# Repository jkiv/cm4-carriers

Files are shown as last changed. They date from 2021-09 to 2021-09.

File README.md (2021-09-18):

# cm4-carriers

## About

This repository contains various Raspberry Pi Compute Module 4 (CM4) carrier boards designed with specific applications in mind.

It also contains "template" boards from which application-specific boards can be quickly derived.

## Boards

### cm4-carrier-net

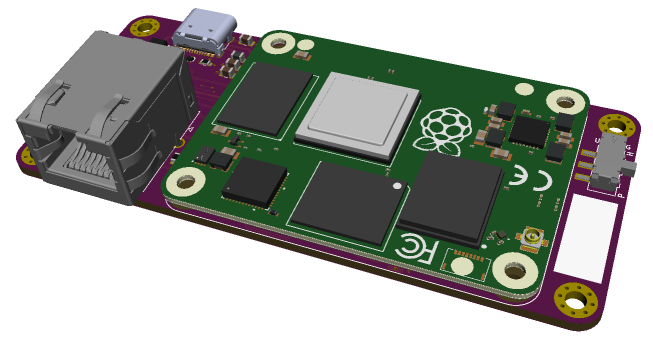
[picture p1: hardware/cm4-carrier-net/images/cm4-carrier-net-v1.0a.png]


#### About
A carrier board that provides the CM4 with an Ethernet interface.

This board can also be used to program the eMMC memory for use on other carrier boards.

#### Features
* Gigabit Ethernet
* USB Type-C 5V power and data (USB 2.0)
* Micro SD card slot

## Donate

Please consider supporting this project and others like it by donating:

* ☕: [ko-fi.com/jkiv_](https://ko-fi.com/jkiv_)
* ₿: `13zRrs1YDdooUN5WtfXRSDn8KnJdok4qG9`

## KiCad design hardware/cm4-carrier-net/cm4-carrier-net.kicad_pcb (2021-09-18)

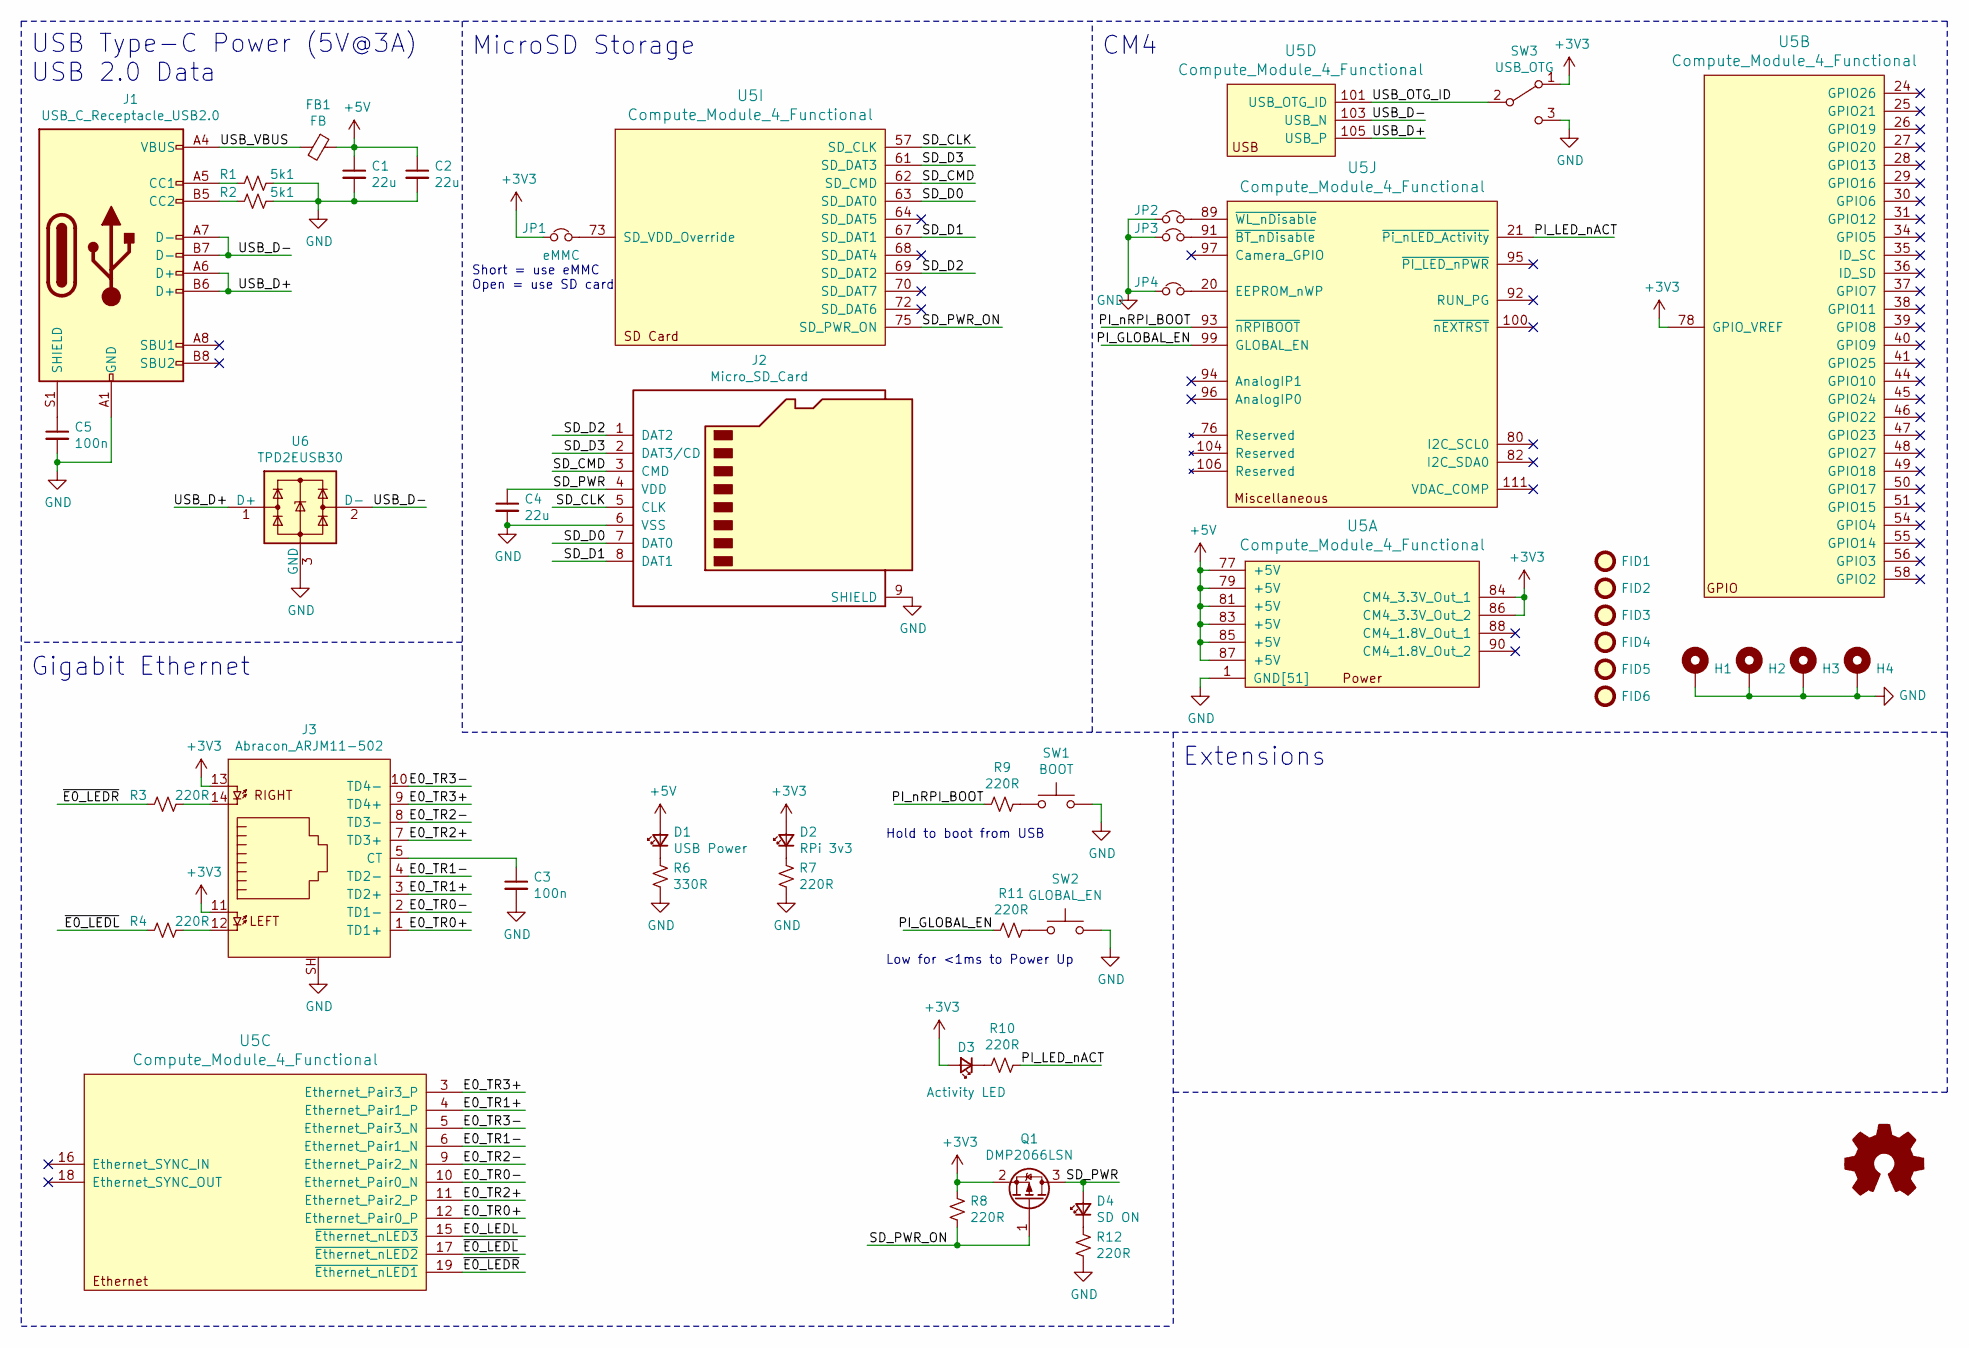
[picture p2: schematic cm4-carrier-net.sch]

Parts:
C1, C2, C4: 22u; C_0805_2012Metric
C3, C5: 100n; C_0805_2012Metric
D1: USB Power; LED_0603_1608Metric
D2: RPi 3v3; LED_0603_1608Metric
D3: Activity LED; LED_0603_1608Metric
D4: SD ON; LED_0603_1608Metric
FB1: FB; L_0805_2012Metric
FID1, FID2, FID3, FID4, FID5, FID6: Fiducial; Fiducial_0.75mm_Mask1.5mm
H1, H2, H3, H4: MountingHole_Pad; MountingHole_2.7mm_M2.5_Pad_Via
J1: USB_C_Receptacle_USB2.0; USB_C_Receptacle_GCT-USB4105
J2: Micro_SD_Card; microSD_HC_Molex_104031-0811
J3: Abracon_ARJM11-502; RJ45_Abracon_ARJM11
JP1: eMMC; J_Small_NC
JP2: ~WL_nDisable; J_Small_NC
JP3: ~BT_nDisable; J_Small_NC
JP4: EEPROM_nWP; J_Small_NC
LOGO1: Logo_Open_Hardware_Small; OSHW-Symbol_6.7x6mm_Copper
Q1: DMP2066LSN; SC-59
R1, R2: 5k1; R_0603_1608Metric
R3, R4, R7, R8, R9, R10, R11, R12: 220R; R_0603_1608Metric
R6: 330R; R_0603_1608Metric
SW1: BOOT; SW_SPST_B3U-1000P
SW2: GLOBAL_EN; SW_SPST_B3U-1000P
SW3: USB_OTG; SW_SPDT_CK-JS102011SAQN
U5: Compute_Module_4_Functional; Raspberry-Pi-4-Compute-Module
U6: TPD2EUSB30; Texas_DRT-3

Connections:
+3V3: D2.2 (A), D3.2 (A), J3.11, J3.13, JP1.1, Q1.2 (S), R8.2, SW3.1 (A), U5.78 (GPIO_VREF), U5.84 (CM4_3.3V_Out_1), U5.86 (CM4_3.3V_Out_2)
+5V: C1.1, C2.1, D1.2 (A), FB1.1, U5.77 (+5V), U5.79 (+5V), U5.81 (+5V), U5.83 (+5V), U5.85 (+5V), U5.87 (+5V)
/E0_LEDL: U5.15 (~Ethernet_nLED3)
/E0_TR0+: J3.1 (TD1+), U5.12 (Ethernet_Pair0_P)
/E0_TR0-: J3.2 (TD1-), U5.10 (Ethernet_Pair0_N)
/E0_TR1+: J3.3 (TD2+), U5.4 (Ethernet_Pair1_P)
/E0_TR1-: J3.4 (TD2-), U5.6 (Ethernet_Pair1_N)
/E0_TR2+: J3.7 (TD3+), U5.11 (Ethernet_Pair2_P)
/E0_TR2-: J3.8 (TD3-), U5.9 (Ethernet_Pair2_N)
/E0_TR3+: J3.9 (TD4+), U5.3 (Ethernet_Pair3_P)
/E0_TR3-: J3.10 (TD4-), U5.5 (Ethernet_Pair3_N)
/PI_GLOBAL_EN: R11.2, U5.99 (GLOBAL_EN)
/PI_LED_nACT: R10.1, U5.21 (~Pi_nLED_Activity)
/PI_nRPI_BOOT: R9.2, U5.93 (~nRPIBOOT)
/SD_CLK: J2.5 (CLK), U5.57 (SD_CLK)
/SD_CMD: J2.3 (CMD), U5.62 (SD_CMD)
/SD_D0: J2.7 (DAT0), U5.63 (SD_DAT0)
/SD_D1: J2.8 (DAT1), U5.67 (SD_DAT1)
/SD_D2: J2.1 (DAT2), U5.69 (SD_DAT2)
/SD_D3: J2.2 (DAT3/CD), U5.61 (SD_DAT3)
/SD_PWR: C4.1, D4.2 (A), J2.4 (VDD), Q1.3 (D)
/SD_PWR_ON: Q1.1 (G), R8.1, U5.75 (SD_PWR_ON)
/USB_D+: J1.A6 (D+), J1.B6 (D+), U5.105 (USB_P), U6.1 (D+)
/USB_D-: J1.A7 (D-), J1.B7 (D-), U5.103 (USB_N), U6.2 (D-)
/USB_OTG_ID: SW3.2 (B), U5.101 (USB_OTG_ID)
/USB_VBUS: FB1.2, J1.A4 (VBUS), J1.A9 (VBUS), J1.B4 (VBUS), J1.B9 (VBUS)
/~E0_LEDL: R4.2, U5.17 (~Ethernet_nLED2)
/~E0_LEDR: R3.2, U5.19 (~Ethernet_nLED1)
GND: C1.2, C2.2, C3.2, C4.2, C5.2, H1.1, H2.1, H3.1, H4.1, J1.A1 (GND), J1.A12 (GND), J1.B1 (GND), J1.B12 (GND), J2.6 (VSS), J2.9 (SHIELD), J3.SH, JP2.1, JP3.1, JP4.1, R1.1, R2.1, R6.2, R7.2, R12.2, SW1.2, SW2.2, SW3.3 (C), U5.1 (GND[51]), U5.2 (GND[51]), U5.7 (GND[51]), U5.8 (GND[51]), U5.13 (GND[51]), U5.14 (GND[51]), U5.22 (GND[51]), U5.23 (GND[51]), U5.32 (GND[51]), U5.33 (GND[51]), U5.42 (GND[51]), U5.43 (GND[51]), U5.52 (GND[51]), U5.53 (GND[51]), U5.59 (GND[51]), U5.60 (GND[51]), U5.65 (GND[51]), U5.66 (GND[51]), U5.71 (GND[51]), U5.74 (GND[51]), U5.98 (GND[51]), U5.107 (GND[51]), U5.108 (GND[51]), U5.113 (GND[51]), U5.114 (GND[51]), U5.119 (GND[51]), U5.120 (GND[51]), U5.125 (GND[51]), U5.126 (GND[51]), U5.131 (GND[51]), U5.132 (GND[51]), U5.137 (GND[51]), U5.138 (GND[51]), U5.144 (GND[51]), U5.150 (GND[51]), U5.155 (GND[51]), U5.156 (GND[51]), U5.161 (GND[51]), U5.162 (GND[51]), U5.167 (GND[51]), U5.168 (GND[51]), U5.173 (GND[51]), U5.174 (GND[51]), U5.179 (GND[51]), U5.180 (GND[51]), U5.185 (GND[51]), U5.186 (GND[51]), U5.191 (GND[51]), U5.192 (GND[51]), U5.197 (GND[51]), U5.198 (GND[51]), U6.3 (GND)
unnamed: C3.1, J3.5 (CT), J3.6 (CT)
unnamed: C5.1, J1.S1 (SHIELD)
unnamed: D1.1 (K), R6.1
unnamed: D2.1 (K), R7.1
unnamed: D3.1 (K), R10.2
unnamed: D4.1 (K), R12.1
unnamed: J1.A5 (CC1), R1.2
unnamed: J1.B5 (CC2), R2.2
unnamed: J3.12, R4.1
unnamed: J3.14, R3.1
unnamed: JP1.2, U5.73 (SD_VDD_Override)
unnamed: JP2.2, U5.89 (~WL_nDisable)
unnamed: JP3.2, U5.91 (~BT_nDisable)
unnamed: JP4.2, U5.20 (EEPROM_nWP)
unnamed: R9.1, SW1.1
unnamed: R11.1, SW2.1

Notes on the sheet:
USB Type-C Power (5V@3A) USB 2.0 Data
MicroSD Storage
CM4
Gigabit Ethernet
Extensions
Low for <1ms to Power Up
Short = use eMMC Open = use SD card
Hold to boot from USB

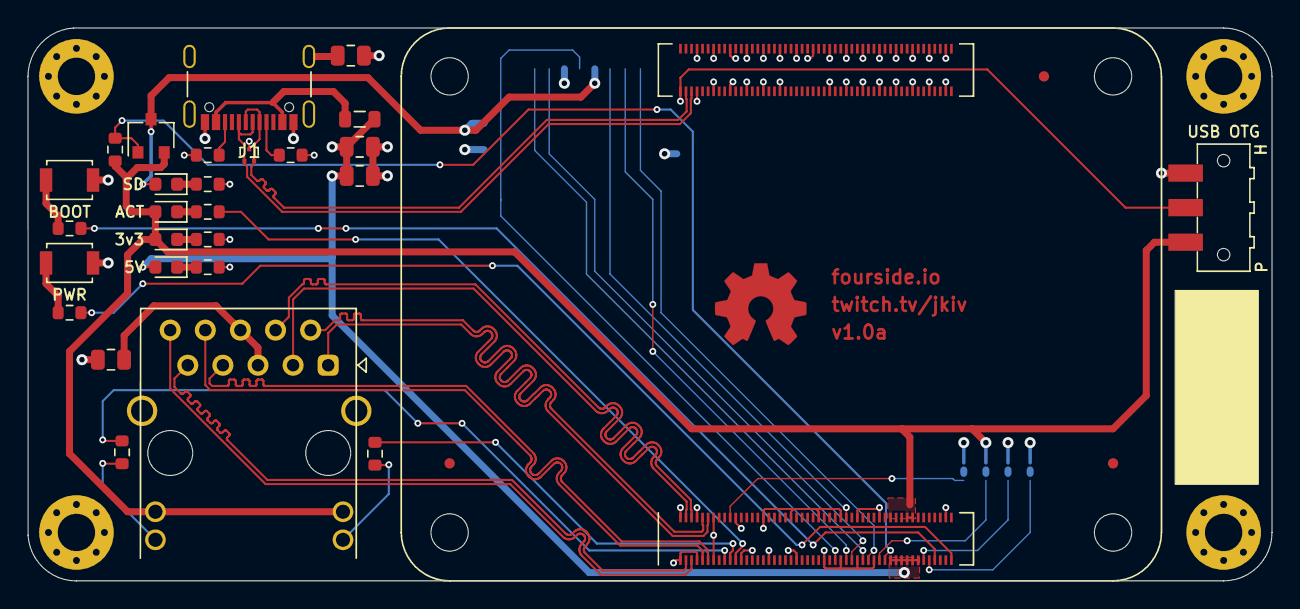
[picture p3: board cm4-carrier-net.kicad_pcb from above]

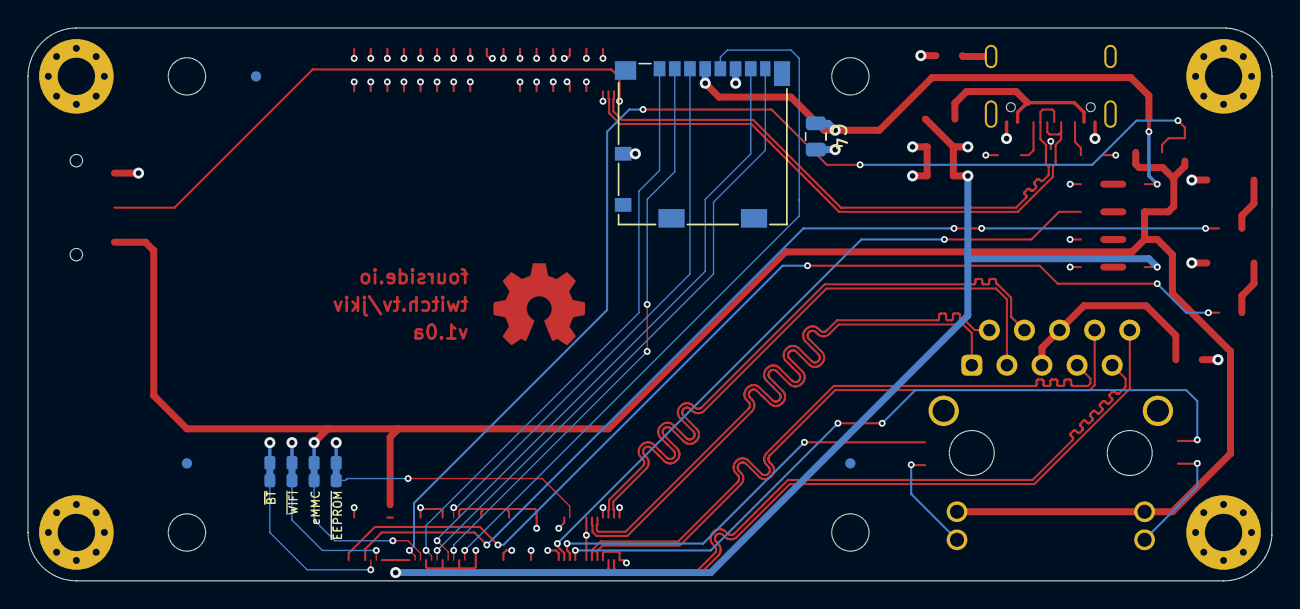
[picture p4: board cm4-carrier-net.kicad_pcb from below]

Board: 4 copper layers, 90.0 x 40.0 mm, 45 parts (9 on the bottom side), 44 nets.

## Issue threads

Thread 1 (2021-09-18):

Add RUN_PG → GLOBAL_EN for GLOBAL_EN button

jkiv, 2021-09-18:
RUN_PG is 5V when running, so button won't shutdown the Pi, 0V when powered down, so button starts the Pi. (TODO test)

jkiv, 2021-09-21:
Not implemented in v1.0a.

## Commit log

2021-09-07 jkiv-kicad-library tracking dev branch.
2021-09-08 Basic CM4 board template -- 90mm x 90mm -- with PoE extension.
    [cm4-carrier-template.sch]
2021-09-08 Forgot to commit PCB.
    [cm4-carrier-template.kicad_pcb]
2021-09-12 Post-stream commit.
    [cm4-carrier-template.kicad_pcb, cm4-carrier-template.sch]
2021-09-17 Pre-stream commit.
    [cm4-carrier-template.kicad_pcb, cm4-carrier-template.sch]
2021-09-17 Finished layout for 40mmx90mm base carrier.
    [cm4-carrier-template.kicad_pcb, cm4-carrier-template.sch]
2021-09-17 Tracking up-to-date jkiv-kicad-library
2021-09-17 Small adjustment to signal paths to make space on backside.
    [cm4-carrier-template.kicad_pcb]
2021-09-17 Fixed disconnected 'SD enabled' LED.
    [cm4-carrier-template.kicad_pcb, cm4-carrier-template.sch]
2021-09-17 Ok. Symbol libraries /should/ be fixed... 🤞
    [cm4-carrier-template.sch]
2021-09-17 Updated USB connector to what is available. Generated gerbers, HTMLBOM.
    [cm4-carrier-template-B_Cu.gbl, cm4-carrier-template-B_Mask.gbs, cm4-carrier-template-B_Paste.gbp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]
2021-09-17 Renaming 40mmx90mm gigabit Ethernet board to cm4-carrier-net.
    [cm4-carrier-net-B_Cu.gbl, cm4-carrier-net-B_Mask.gbs, cm4-carrier-net-B_Paste.gbp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]
2021-09-17 Updated metadata for cm4-carrier-net PCB.
    [cm4-carrier-net.kicad_pcb]
2021-09-17 Added 90mm x 90mm 'template' schematic and PCB.
    [cm4-carrier-template.kicad_pcb, cm4-carrier-template.sch]
2021-09-18 Added USB OTG ID selection switch. Likely finalized v1.0a.
    [cm4-carrier-net-B_Cu.gbl, cm4-carrier-net-B_Mask.gbs, cm4-carrier-net-B_Paste.gbp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]
